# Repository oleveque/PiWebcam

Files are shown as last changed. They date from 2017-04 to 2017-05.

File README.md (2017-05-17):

# PiWebcam
* Rémi Armand, *remi.armand@ens-paris-saclay.fr*
* Olivier Lévêque, *olivier.leveque@ens-paris-saclay.fr*

Ce projet, proposé en M2 FeSUP GE à l'École Normale Supérieure Paris-Saclay, a pour objectif de réaliser un système permettant de commander l’orientation d’une webcam à partir d’un serveur web embarqué. Il se base sur l'utilisation d'une *Raspberry Pi 3* et d'un microcontrôleur *AVR-T32U4* (similaire à une *Arduino Leonardo*).

Ce système, nommé *PiWebcam*, vous est présenté en image ci-dessous.
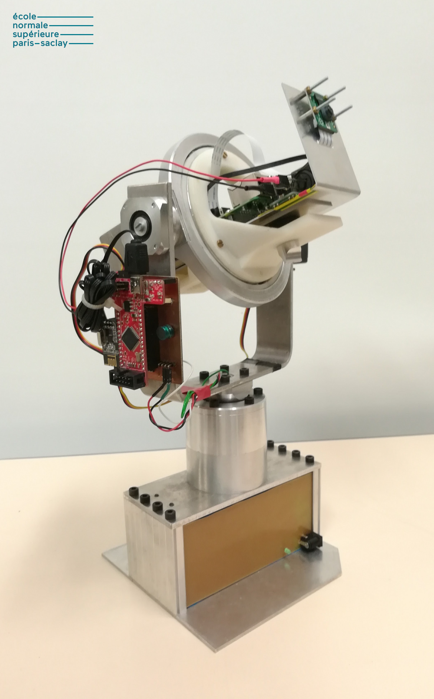
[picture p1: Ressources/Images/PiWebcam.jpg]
PiWebcam


Nous décrirons dans ce manuel son fonctionnement et nous détaillerons son installation et sa configuration.

La chronologie adoptée sera la suivante :
1. Description globale du système ;
2. Configuration du microcontrôleur *AVR-T32U4* ;
3. Installation et configuration de l'ensemble du système Linux sur *Raspberry Pi 3*.

## Description globale du système
Le système PiWebcam répond à la problématique suivante.
> Piloter une webcam à distance en commandant son orientation et son zoom à l’aide d’un serveur embarqué.

La partie matériel, nommé *Cardan 3 axes* et permettant l'orientation de la caméra, est issue d'un projet ultérieur. Seul l'étage d'alimentation a été révisé et une *Raspberry Pi 3* + *PiCamera v2.1* ajoutées. Le diagramme de définition de bloc suivant permet de décomposer le système *PiWebcam* en différents sous-systèmes que nous décrirons dans ce document.

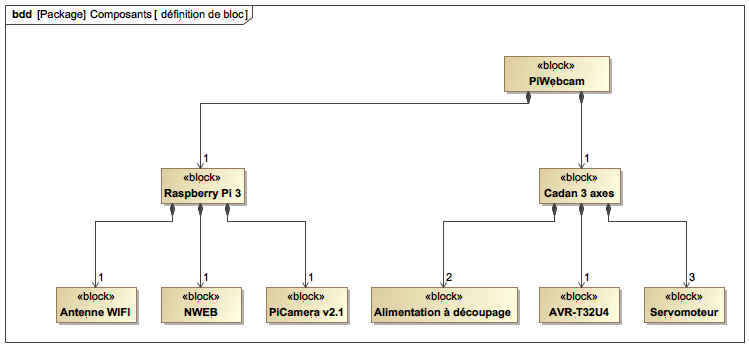
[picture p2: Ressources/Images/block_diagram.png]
Diagramme de définition de bloc


### Cardan 3 axes
Ce sous-système est composé de 2 servomoteurs ([*HS-5565MH*](Ressources/Datasheets/hs5565.pdf)) commandés en position assurant la rotation de la caméra autour de l'axe de roulis et l'axe de tangage, et d'un servomoteur ([*HS-805BB*](Ressources/Datasheets/hs805.pdf)) modifié assurant la rotation de la caméra autour de l'axe de lacet. Ce dernier est commandé en vitesse et permet une rotation totale de la caméra autour de son axe puisque sa butée mécanique a été retirée et son potentiomètre de recopie remplacé par un pont diviseur de tension.

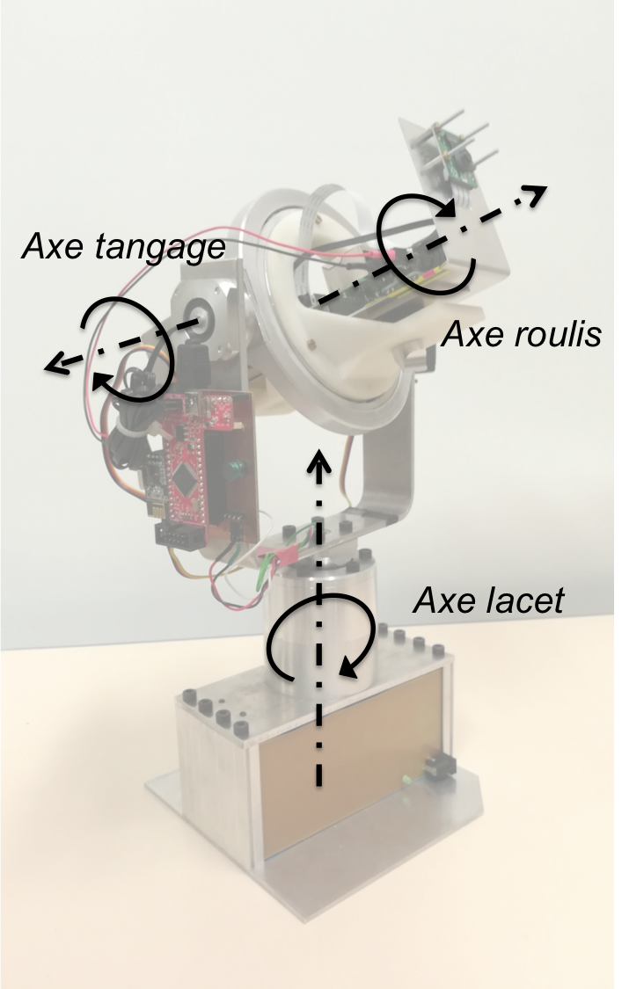
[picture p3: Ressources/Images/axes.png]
axes


Le schéma suivant décrit sommairement le système.

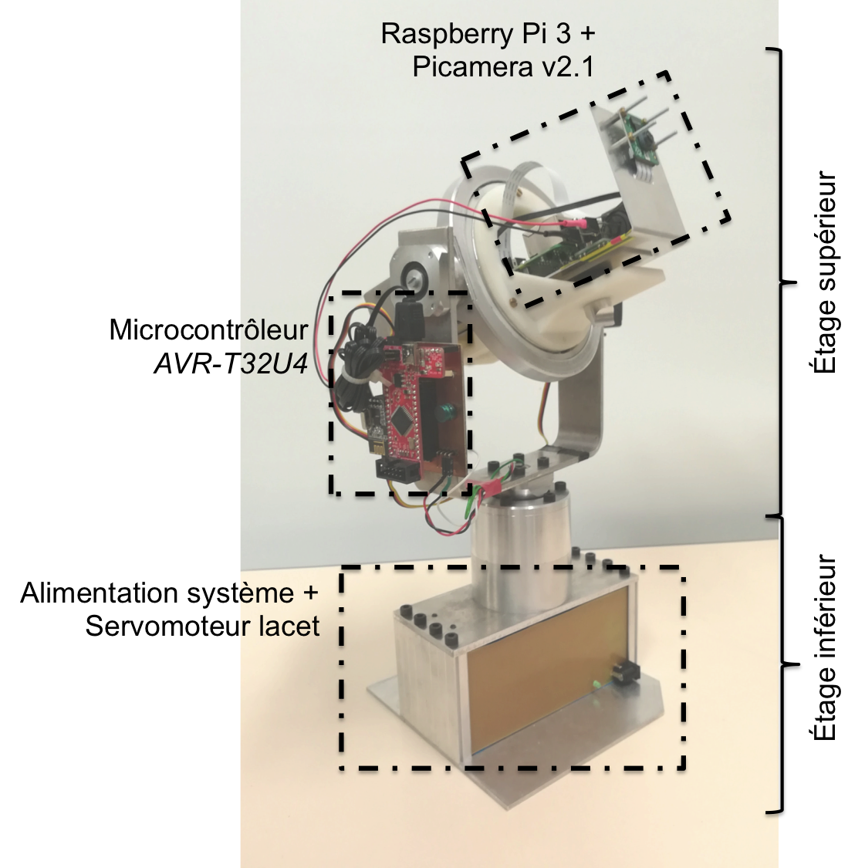
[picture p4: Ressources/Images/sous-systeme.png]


La liaison électrique entre l'étage supérieur et inférieur est assuré par des contacts glissants, permettant une rotation complète de l'étage supérieur.

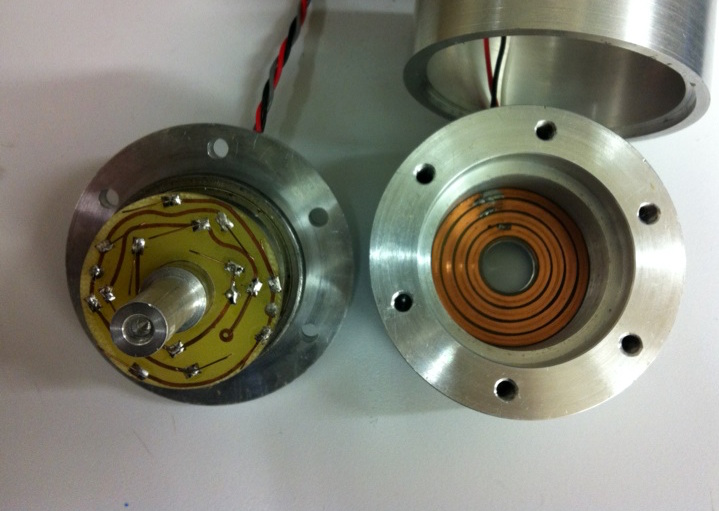
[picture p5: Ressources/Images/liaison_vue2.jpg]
contacts


L’étage d'alimentation est situé dans la botte du système (étage inférieur) et est assuré par 2 alimentations à découpage (*LM2596* et *MP2307*) délivrant (respectivement) 5V et 7V. Les fichiers *EAGLE* de cet étage sont disponibles dans l'archive du projet.
* Les 5V permettent l’alimentation du servomoteur inférieur assurant la rotation autour de l'axe de lacet ;
* Les 7V permettent l’alimentation des servomoteurs restants, du microcontrôleur, et de la Raspberry. Deux régulateurs linéaires (*L7805CV* et *79ABN05A*) permettent de fournir les 3.3V nécessaire au microcontrôleur et une 3ième alimentation à découpage (*MP2307*) permet de fournir 5V à la Raspberry. Sur cette dernière alimentation, une capacité de 2200uF a été ajoutée en entrée pour diminuer les chutes de tension lors des appels de courant des servomoteurs.

Le schéma suivant illustre la répartion de l'alimentation au sein du système.

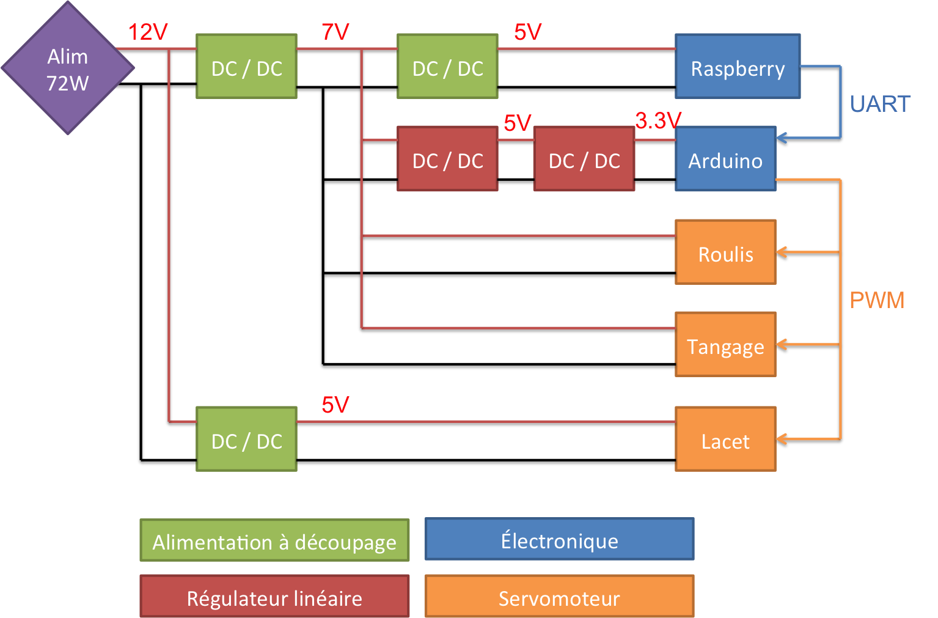
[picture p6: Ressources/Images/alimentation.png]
Schéma d'alimentation


La carte de développement utilisé est une *AVR-T32U4* dont l'architecture est inspirée d’une *Arduino Leonardo*. Elle peut être programmée à partir de l’*IDE Arduino*.
Le rôle du microcontrôleur est d'assurer le pilotage des 3 servomoteurs. Les différents pins utilisés de la carte sont présentés sur le schéma suivant.

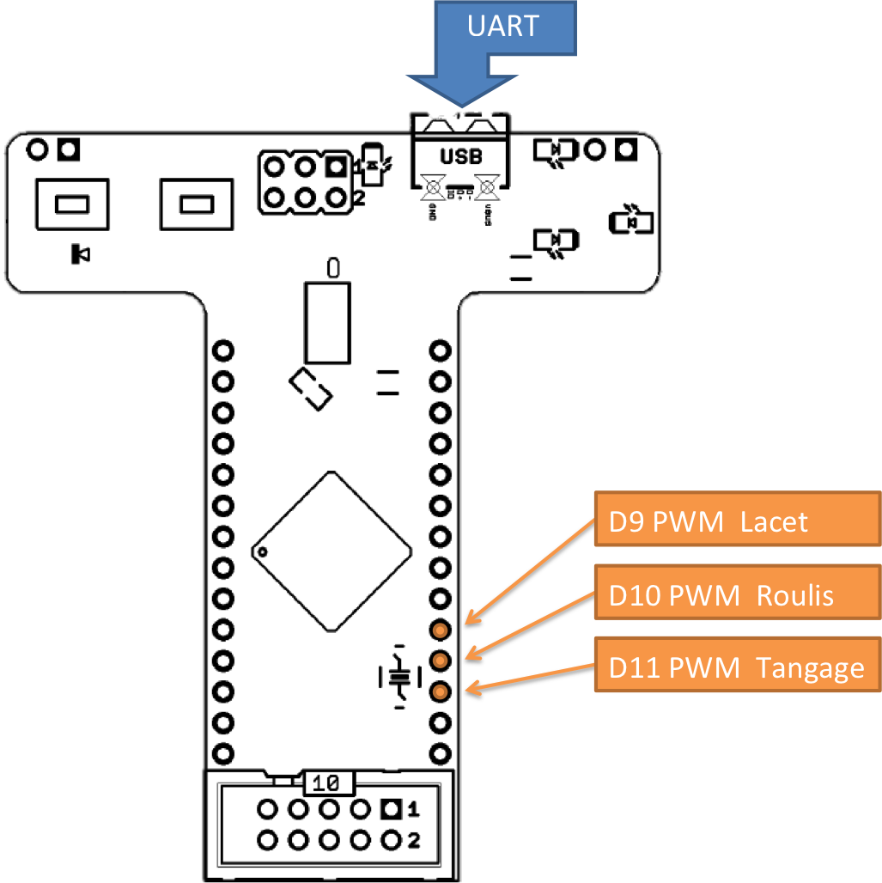
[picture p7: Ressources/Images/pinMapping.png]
Pin mapping


La communication entre la Raspberry et le microcontrôleur peut être assurée par différents types de liaison (I2C, SPI, UART). La liaison série à travers une connection USB a été retenue pour 2 raisons principales : sa facilité de mise en oeuvre et la possibilité de reprogrammer l'*AVR-T32U4* à partir de la Raspberry.

### Raspberry Pi 3 + PiCamera
La *Raspberry Pi 3* hébergera le serveur à partir duquel l'utilisateur devra se connecter pour piloter le système et visualiser le flux vidéo de la *PiCamera v2.1* (cette caméra a une résolution de 8 mégapixels permettant la mise en oeuvre d'un zoom numérique).

Le serveur diffusera une interface graphique dans lequel le flux vidéo sera streamé. Des boutons permettront de transmettre des ordres au différents servomoteurs via une liaison série entre la Raspberry et le microcontrôleur.

Un screenshot de cette interface vous est présenté ci-dessous.

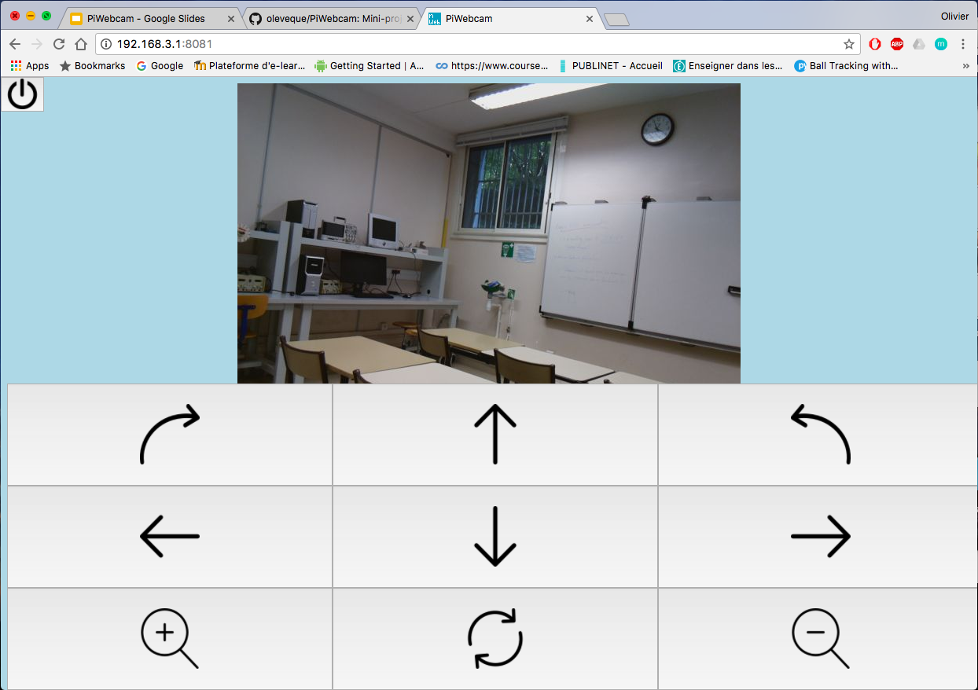
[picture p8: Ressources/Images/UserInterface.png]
User interface


Afin de mieux visualiser les flux d'informations circulant au sein de la Raspberry, le diagramme de bloc interne ci-dessous illustre les flux principaux.

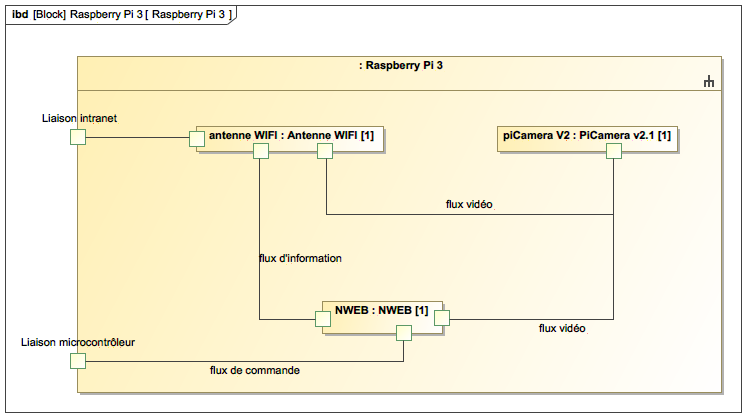
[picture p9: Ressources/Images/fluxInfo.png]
Diagramme Interne


## Configuration du microcontrôleur *AVR-T32U4*
Pour configurer le microcontrôleur *AVR-T32U4*, il est nécessaire de télécharger l'[IDE Arduino](https://www.arduino.cc/en/Main/Software). Il ne vous restera plus qu'à reprogrammer la carte avec l'un des codes *.ino* disponiblent dans le dossier `Arduino/config` (en choissisant le type de board : *Arduino Leonardo*).
Deux codes vous sont proposés :
* `ArduinoPWM.ino` utilisant la blibliothèque *Servo* d'Arduino pour générer la PWM de commande des servomoteurs ;
* `MyOwnPWM.ino` exploitant les capacités matérielles du microcontrôleur pour générer les PWM. Pour mieux comprendre son fonctionnement, vous pouvez consulter [ce lien](http://r6500.blogspot.ca/2014/12/fast-pwm-on-arduino-leonardo.html) et/ou étudier le code `PWM.ino` dans le dossier `Arduino` qui permet de générer des signaux PWM sur les pins D9, D10, D11 de l'*AVR-T32U4*.

Par défaut, ces codes permettent de commander les servomoteurs via une communication unidirectionnelle série de la Raspberry vers le port `Serial0` du microcontrôleur à la vitesse de *9600 baud*.

Les messages à envoyer sont de simples octets répertoriés dans le tableau ci-dessous.

| Octet | Signification |
| ----- | --- |
| `#` | Retour à la position d'origine |
| `@` | Stopper le mouvement et maintenir la position |
| `U` | Rotation autour de l'axe de tangage dans le sens positif |
| `D` | Rotation autour de l'axe de tangage dans le sens négatif |
| `R` | Rotation autour de l'axe de lacet dans le sens positif |
| `L` | Rotation autour de l'axe de lacet dans le sens positif |
| `W` | Rotation autour de l'axe de roulis dans le sens positif  |
| `V` | Rotation autour de l'axe de roulis dans le sens négatif  |

Il est possible d'envoyer un ordre similtanément aux 3 servomoteurs en transmettant l'octet `#` suivit respectivement des positions angulaires des servomoteurs associé au roulis, au tangage et la vitesse angulaire du servomoteur associé au lacet, en séparant les données par un caractère quelconque : par exemple `#350/-260/40`.

## Installation et configuration de l'ensemble du système Linux sur *Raspberry Pi 3*
1. Installation de Raspbian ;
2. Configuration du point d’accès Wifi ;
3. Configuration du streaming vidéo pour une *PiCamera* ;
4. Installation du serveur *nweb* modifié ;
5. Configuration de la communication série entre l'Arduino et Linux TTY ;
6. Configuration du lancement automatique des différents processus au démarrage du système.

Une fois configuré, l'interface de pilotage est accéssible à l'adresse `192.168.3.1:8081` sous réserve d'être connecté au réseau Wifi `PiWebcam` (mot de passe : `mdppiwebcam`) généré par le système.

### Installation de Raspbian
Pour télécharger l'image, rendez-vous sur la [page officiel](https://www.raspberrypi.org/downloads/raspbian/).
Suivez le [guide d'installation](https://www.raspberrypi.org/documentation/installation/installing-images/) si vous ne savez pas (ou plus) comment installer cette image sur une carte SD.

### Configuration du point d’accès Wifi
La configuration du point d'accès Wifi est inspiré de [ce tutoriel](https://www.g33k-zone.org/post/2016/05/11/Configurer-le-Raspberry-Pi-en-point-d-acc%C3%A8s-Wifi).

Cette configuration est valable pour une *Raspberry Pi 3* disposant d'un module Wifi intégré. Il est cependant possible d'effectuer une configuration similaire sur un autre modèle à l'aide d'un dongle Wifi.

**Remarque :** Pour effectuer cette configuration, il est nécessaire d'être directement connecté à la Raspberry avec un moniteur, un clavier + souris, et une connection internet.

Commencez par installer les packages *dnsmasq* et *hostapd*.
```
sudo apt-get install dnsmasq hostapd
```

La première étape consiste à forcer l'adresse IP pour le point d'accès. Par défaut, le wifi de Raspberry étant en *dhcp*, nous allons devoir éditer `/etc/dhcpcd.conf` pour forcer une adresse IP statique (`192.168.3.1` dans notre cas), en ajoutant les lignes suivantes :
```
interface wlan0  
   static ip_address=192.168.3.1/24
```

Ensuite, nous allons bloquer la négociation automatique de bail dans le fichier `/etc/network/interfaces`.
Il faut rechercher le bloc suivant :
```
allow-hotplug wlan0  
iface wlan0 inet manual  
 #   wpa-conf /etc/wpa_supplicant/wpa_supplicant.conf
```

 Il suffit de commenter la ligne d'appel à `wpa_supplicant.conf` (en ajoutant le `#`).

Nous pouvons maintenant redémarrer le wifi à l'aide de la commande suivante.
```
sudo service dhcpcd restart
```

*hostapd* est le logiciel qui permet de gérer le point d'accès, il est donc le coeur de notre système. Sa configuration se fait dans le fichier `/etc/hostapd/hostapd.conf` qu'il faut créer :

```
cd /etc/hostapd/
sudo touch hostapd.conf
sudo nano hostapd.conf
```

Et le remplir avec :
```
# Nom de l'interface wifi (celle par défaut)
interface=wlan0
# Utilisation du driver nl80211,
driver=nl80211
# Nom du réseau wifi (SSID)
ssid=PiWebcam
# Mode du wifi (bande 2.4GHz)
hw_mode=g
# Canal 6
channel=6
# Activer le 802.11n
ieee80211n=1
# Activer le WMM
wmm_enabled=1
# Activer les canaux 40MHz avec 20ns d'intervalle
ht_capab=[HT40][SHORT-GI-20][DSSS_CCK-40]
# Accepter toutes les adresses MAC (pas de restriction d'appareil)
macaddr_acl=0
# Utiliser l'authentification WPA
auth_algs=1
# Ne pas diffuser le SSID
ignore_broadcast_ssid=0
# Utiliser WPA2
wpa=2
# Utiliser une clé partagée
wpa_key_mgmt=WPA-PSK
# Mot de passe du réseau
wpa_passphrase=mdppiwebcam
# Utilisation d'AES plutôt que de TKIP
rsn_pairwise=CCMP
```

Nous pouvons alors à présent tester le fonctionnement du point d'accès.
```
sudo /usr/sbin/hostapd  /etc/hostapd/hostapd.conf
```
Cette commande lance le point d'accès et permet d'avoir le log d'activité directement dans la console. Avec un équipement wifi (gsm, tablette, portable, ...), essayez de vous connecter au réseau `PiWebcam`, normalement la tentative de connexion apparaît.

Une fois que le point d'accès fonctionne, coupez le (*Ctrl+C*) et placez le en démarrage automatique, en éditant le fichier `/etc/default/hostapd`.
```
#DAEMON_CONF=""         =>           DAEMON_CONF="/etc/hostapd/hostapd.conf"
```

*dnsmasq* est un petit serveur DNS qui intègre un serveur *DHCP*. Il permettra d'attribuer les adresses IP aux clients qui se connecteront sur le point d'accès.
Sauvegardez son fichier de configuration initial (`/etc/dnsmasq.conf`, qui n'est pas entierement commenté!) puis créez en une nouvelle version :
```
# Interface à utiliser
interface=wlan0
# Limiter le fonctionnement à l'interface déclarée
bind-interfaces
# Transférer les requêtes DNS sur les DNS d'OpenDns
server=208.67.222.222
# Ne pas forwarder les requêtes "locales" (sans nom de domaine)
domain-needed
# Fausse résolution inverse pour les réseaux privés. Toutes les requêtes DNS inverses pour des adresses IP privées (ie 192.168.x.x, etc…) qui ne sont pas trouvées dans /etc/hosts ou dans le fichier de baux DHCP se voient retournées une réponse “pas de tel domaine” (”no such domain”) au lieu d’être transmises
bogus-priv
# Plage DHCP : on attribuera les adresses IP entre 192.168.3.50 et 192.168.3.150 pour une durée de 12h
dhcp-range=192.168.3.50,192.168.3.150,12h
```

Vous avez actuellement un point d'accès fonctionnel mais limité au réseau local. La suite de ce tutoriel est facultative si vous ne souhaitez pas d'accès à internet via votre Raspberry.

Nous allons utiliser *iptables* pour ajouter des règles de routage.

Il faut commencer par modifier les règles de sécurité dans `/etc/sysctl.conf` pour autoriser le transfert IPv4 (ou IP forwarding) en décommantant la ligne suivante.
```
net.ipv4.ip_forward=1
```

Cette modification ne sera prise en compte qu'au prochain redémarrage de votre Raspberry, mais il est possible de forcer son activation immédiate à l'aide de la commande suivante.
```
sudo sh -c "echo 1 > /proc/sys/net/ipv4/ip_forward"
```

Maintenant que le transfert IPv4 est autorisé, nous allons créer les règles qui vont transférer les requêtes Wifi vers le port ethernet en excécutant les commandes suivantes.
```
sudo iptables -t nat -A POSTROUTING -o eth0 -j MASQUERADE  
sudo iptables -A FORWARD -i eth0 -o wlan0 -m state --state RELATED,ESTABLISHED -j ACCEPT  
sudo iptables -A FORWARD -i wlan0 -o eth0 -j ACCEPT
```

Pour que ces règles soient appliquées à chaque démarrage, nous allons commencer par les sauvegarder dans un fichier `/etc/iptables.ipv4.nat`.
```
sudo sh -c "iptables-save > /etc/iptables.ipv4.nat"
```

Ensuite, nous allons créer un fichier qui sera appelé automatiquement au démarrage du serveur *dhcp*
```
sudo echo "iptables-restore < /etc/iptables.ipv4.nat" > /lib/dhcpcd/dhcpcd-hooks/70-ipv4-nat
```

Pour pouvoir tester votre système sans avoir à le rebooter, il suffit de lancer les daemons manuellement.
```
sudo service hostapd start  
sudo service dnsmasq start
```

Vous disposez à présent dans point d'accés Wifi via la Raspberry.

### Configuration du streaming vidéo pour une *PiCamera*
Pour le streaming vidéo, nous utilisons le package *mjpg-streamer*. Pour plus d'informations, suivez [ce lien](https://doc.ubuntu-fr.org/mjpg-streamer).

Avant de commencer, assurez vous que le package *subversion* est bien installé.
```
sudo apt-get install subversion
```

L'installation de *mjpg-streamer* peut alors commencer.
```
sudo apt-get install libjpeg62-dev
sudo apt-get install libjpeg-dev
svn checkout svn://svn.code.sf.net/p/mjpg-streamer/code/  /mjpg-streamer
cd /mjpg-streamer/mjpg-streamer
sudo make
sudo make install
```

Pour pouvoir lancer le streaming vidéo, il faut charger le module `bcm2835-v4l2` à l'aide de la commande suivante à chaque démarrage de la Raspberry. La camera doit être branché au démarrage. Pour plus d'informations, consultez [ce lien](http://www.epingle.info/?p=3224).
```
sudo modprobe bcm2835-v4l2
```

Pour éviter d’avoir à exécuter cette commande à chaque démarrage, il suffit d’ajouter le module `bcm2835-v4l2` à l’ensemble des modules lancés par Linux au démarrage en ajoutant le nom du module à la fin du fichier  `/etc/modules`.

Le streaming vidéo se lance à l'aide de la commande suivante.
```
mjpg_streamer -i "/usr/local/lib/input_uvc.so -d /dev/video0 -f 24 -r 320x180" -o "/usr/local/lib/output_http.so -n -w /usr/local/www -p 8001"
```
La vérification de l'existence de `/dev/video0` permet de savoir sur le module s’est bien lancer au démarrage.

Le flux vidéo de la *PiCamera* devrait à présent être accessible à l'adresse `192.168.3.1:8001`.

### Installation du serveur *nweb* modifié
La serveur web mis en oeuvre repose sur le serveur *nweb* proposé par [Ankush Agarwal](https://github.com/ankushagarwal/nweb). Nous l'avons légèrement modifié pour qu'il prennent en compte la gestion de *cgi*.

Pour l'installer, placez le fichier `nweb23.c` et le dossier `serveur` contenant le site dans un répertoire sensible (et non pas dans un répertoire système comme `/` ou `/temp`). Par exemple dans `/home`. Puis rendez le dossier lisible.
```
chmod ugo+r /home/serveur
```
Compilez ensuite le serveur *nweb* et rendez le executable.
```
cc /home/nweb23.c -o /home/nweb
chmod 777 /home/nweb
```
Décidez ensuite du numéro du port que vous utiliserez (ici *8081*). Puis lancez *nweb* à l'aide de la commande suivante.
```
/home/nweb 8081 /home/serveur
```

Voilà, le serveur *nweb* fonctionne à présent et l'interface de pilotage du système *PiWebcam* est disponile à l'adresse `192.168.3.1:8081`

### Configuration de la communication série entre l'Arduino et Linux TTY
Pour configurer la connection Série entre la Raspberry et le microcontrôleur avec la bonne parité, vitesse... excécutez la commande suivante. Pour plus d'information, consultez [ce lien](http://playground.arduino.cc/Interfacing/LinuxTTY).
```
stty -F /dev/ttyACM0 cs8 9600 ignbrk -brkint -icrnl -imaxbel -opost -onlcr -isig -icanon -iexten -echo -echoe -echok -echoctl -echoke noflsh -ixon -crtscts
```

Pour envoyer un message de type *String* au microcontrôleur, nous utiliserons les commandes :
```
#avec fin de ligne
echo "Hello Arduino" > /dev/ttyUSB0

#sans fin de ligne
echo -n "Hello" > /dev/ttyUSB0
```

Pour lire un message de type String envoyé du microcontrôleur, nous utiliserons la commande :
```
tail -f /dev/ttyUSB0
```

### Lancement des différents processus au démarrage de la Raspberry
Le lancement du serveur *nweb* et du streaming vidéo au démarrage de la Raspberry se fait à l'aide du fichier `lancementServeur.sh`. (Nous supposerons que ce fichier disponible dans l'archive du projet et se trouve dans `/home`).

Déplacez le script shell dans le répertoire `/etc/init.d` qui contient les différents scripts lancés au démarrage, et rendait le executable via les commandes suivantes.

```
sudo mv /home/lancementServeur.sh /etc/init.d/lancementServeur
sudo chmod 777 /etc/init.d/lancementServeur
```

Les liens symboliques associés au fichier `lancementServeur` pour son démarrage et son arrêt au lancement et à l'arrêt de la Raspberry sont générés à l'aide de la commande suivante.
```
sudo update-rc.d lancementServeur defaults
```
Le lien symbolique créé dans `rc3.d` est `S02lancementserveur`. Nous pouvons renommer le lien en `S99lancementserveur` pour qu'il se lance en dernier.

À présent le système *PiCamera* est entièrement installé et configuré.

Enjoy & have a lot of fun...

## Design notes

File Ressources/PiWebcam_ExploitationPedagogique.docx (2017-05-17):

TP PiWebcam


Le système PiWebcam est en système pluri-technique répondant à la problématique suivante.

“Piloter une webcam à distance en commandant son orientation et son zoom à l’aide d’un serveur embarqué.”

Une documentation technique associée est disponible, ainsi que la datasheet de la plupart des éléments composants le système.

Nous explorerons durant ce TP le fonctionnement d’un servomoteur usuel et la génération de ses signaux de commande. Nous mettrons en œuvre une PWM hardware en manipulant les registres spécifiques à l’Atmega32U4.

1. Approche globale

Attention : Avant la mise sous tension du système, veuillez lire attentivement la documentation associée et répondre aux questions suivantes.

Q1.1. Établir un tableau récapitulatif des puissances électriques consommés par les différents sous-systèmes de la PiWebcam :

- Servomoteurs (alimenté en 5V, 7V) ;
- Raspberry ;
- microcontrôleur.

Q1.2. Trois adaptateurs secteurs vous sont proposés (1,8W, 30W et 72W). En déduire de la Q1 l’adaptateur le plus approprié pour le bon fonctionnement du système. Présenter et justifier votre résultat à l’enseignant pour qu’il puisse le valider votre choix.

Q1.3. Un condensateur 2200uF a été ajouté en amont de l’alimentation à découpage associée à la Raspberry. Expliciter son rôle ?

Q1.4. Quel type de communication entre la Raspberry et le microcontrôleur est-il mis en œuvre ? D’autres liaisons pourraient-elles être envisagées ?

Q1.5. Les servomoteurs sont-ils commandés en position et/ou vitesse ? Quelles grandeurs physiques les commandent ?

- Tension ;
- Courant ;
- Autres (précisez…)

À présent, alimentez le système avec l’adaptateur retenu et validé à la Q2 et prenez en main le système en vous connectant en Wifi à son intranet.

SSID : PiWebcam

Mot de passe : mdppiwebcam

Attendre deux bonnes minutes que les processus de la Raspberry (mise en route du serveur web, streaming de la webcam…) s’exécutent correctement puis ouvrir un navigateur et taper l'adresse suivante pour accéder à son interface graphique.

192.168.3.1:8081

Manipuler le système via cette interface pour le prendre en main.

Attention : L’extinction de la PiWebcam se fait via l’interface graphique. Ce n’est qu’une fois la LED verte de la Raspberry éteinte que vous pouvez retirer l’alimentation.

2. Commande en position d’un servomoteur

Q2.1. En vous inspirant du programme .ino présent dans le dossier /Arduino/config/ArduinoPWM qui configure le microcontrôleur, écrire un programme simple sous l’IDE Arduino qui permet de piloter la position angulaire de l’arbre de sortie du servomoteur Roulis (pin D10) par largeur d'impulsion. Vous pourrez vous aider de la bibliothèque Servo d’Arduino.

Q2.2. À l’aide d’un oscilloscope, vérifier que la PWM générée est bien celle attendue et tracer à l’aide d’Excel un graphe présentant la valeur angulaire de l’arbre de sortie en fonction de la largeur d’impulsion du signal envoyé (la largeur comprise sera entre 700us à 2200us). Quelle est la nature de cette relation ? Existe-t-il des zones mortes ?

Q2.3. Quels phénomènes non désirés remarqués vous sur la commande des servomoteurs ? Ces phénomènes sont particulièrement visibles sur le système PiWebcam dans sa position de repos (position adoptée au démarrage). Justifier à l’aide de l’oscilloscope que ces phénomènes proviennent des signaux PWM envoyés aux servomoteurs.

3. Générations de PWM hardware

Pour supprimer les phénomènes constatés à la Q8, il est nécessaire de générer des signaux PWM matériellement (sans utiliser la bibliothèque Servo d’Arduino mais les ressources matérielles de l’Atmega32U4).

Q3.1. À partir des datasheets disponibles sur le microcontrôleur, expliquer brièvement comment peut-on générer une PWM à partir d’un Timer. Quels types de PWM peut-on générer avec un Atmega32U4?

Q3.2. Quels périodes doivent avoir les signaux PWM ?

Q3.3. Vu les pins sur lesquels sont branchés les servomoteurs de la PiWebcam, quel Timer pouvons nous utiliser ? Quelle est sa résolution (en nombre de bits) ? Sachant que l’on souhaite une résolution angulaire de 0,1°, sera-t-elle suffisante ? Justifier vos affirmations à l’aide des datasheets des servomoteurs.

Q3.4. Quels registres permettent de configurer le Timer ?

Nous souhaitons mettre en œuvre un signal Fast PWM 16bit utilisant le Timer 1 sur le pin D10 du microcontrôleur, afin de commander le Servo HS-5565 assurant la rotation autour de l'axe de roulis.

Q3.5. À l’aide des réponses précédentes, déterminer le prescaler du Timer et sa valeur MAX.

Q3.6. Comparer vos valeurs d’initialisation des registres avec ceux du programme PWM.ino disponible dans le dossier Arduino. Sont-ils semblables ? Commenter et argumenter vos différences.

Q3.7. Tester le programme et vérifier à l’oscilloscope la PWM généré. Est-elle celle escomptée ?

Q3.8. Le programme MyOwnPWM.ino reprend le programme ArduinoPWM.ino en n’utilisant plus la bibliothèque Servo mais en générant une Fast PWM 16bit comme vu précédemment. Flasher le programme dans le microcontrôleur, retourner sur l’interface graphique de la PiWebcam et piloter le système. Les phonèmes constatés à la Q8 sont-ils toujours présents ? Commenter et justifier vos affirmations.

Rémi Armand Page 1 sur 1 Olivier Lévêque

École normale supérieure Paris-Saclay 17 May 2017

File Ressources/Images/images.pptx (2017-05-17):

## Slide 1

Alim
72W

12V

7V

5V

DC / DC

DC / DC

Raspberry

DC / DC

5V

DC / DC

3.3V

Arduino

UART

Roulis

PWM

Tangage

DC / DC

5V

Lacet

Alimentation à découpage

Électronique

Régulateur linéaire

Servomoteur

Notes: Schéma d’alimentation

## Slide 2

UART

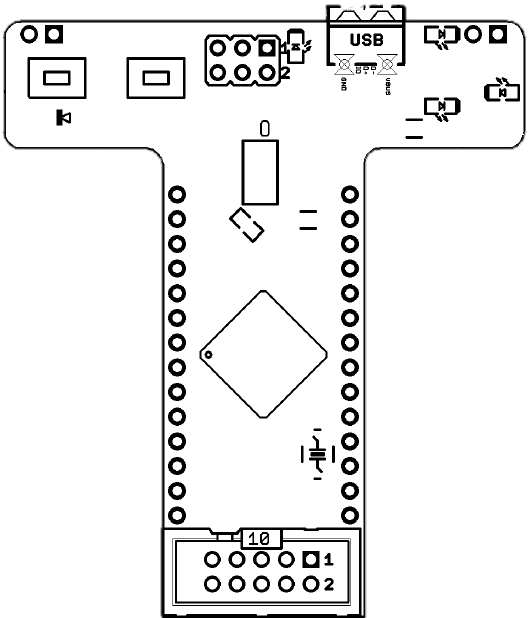
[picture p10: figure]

D9 PWM Lacet

D10 PWM Roulis

D11 PWM Tangage

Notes: Schéma pin mapping

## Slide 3

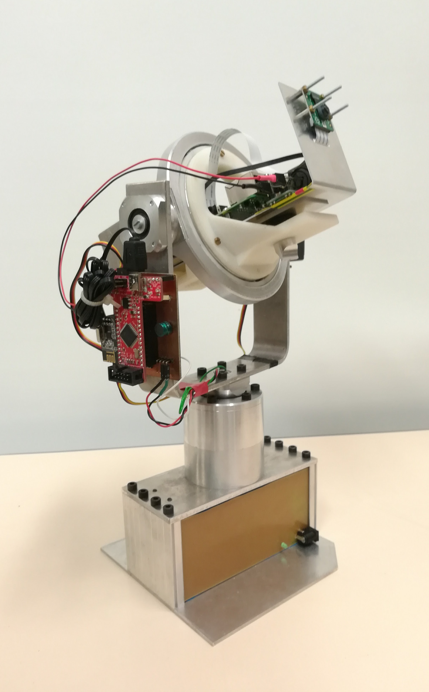
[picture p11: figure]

Axe tangage

Axe roulis

Axe lacet

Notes: Axes de la PiWebcam

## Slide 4

Raspberry Pi 3 +
Picamera v2.1

Étage supérieur

Microcontrôleur
AVR-T32U4

Alimentation système +
Servomoteur lacet

Étage inférieur

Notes: Sous-systèmes

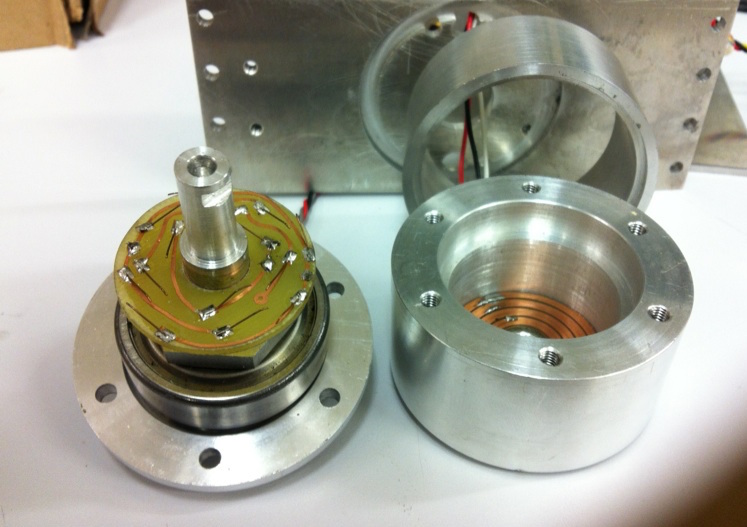
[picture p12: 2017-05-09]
Ressources/Images/liaison_vue1.jpg

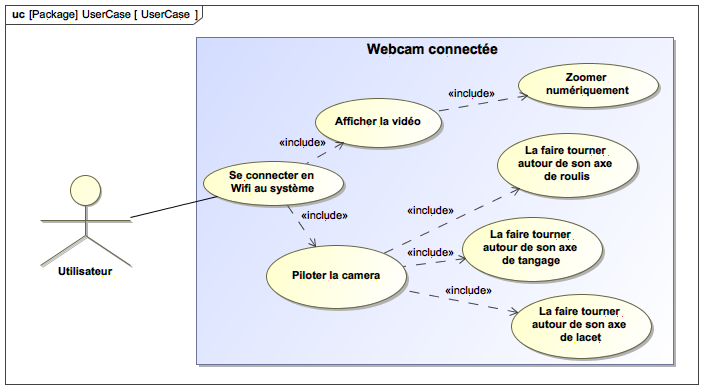
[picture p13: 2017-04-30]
Ressources/Images/UserCase.png

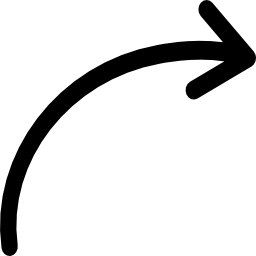
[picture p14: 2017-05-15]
RaspberryPi/serveur/right-roulis.png

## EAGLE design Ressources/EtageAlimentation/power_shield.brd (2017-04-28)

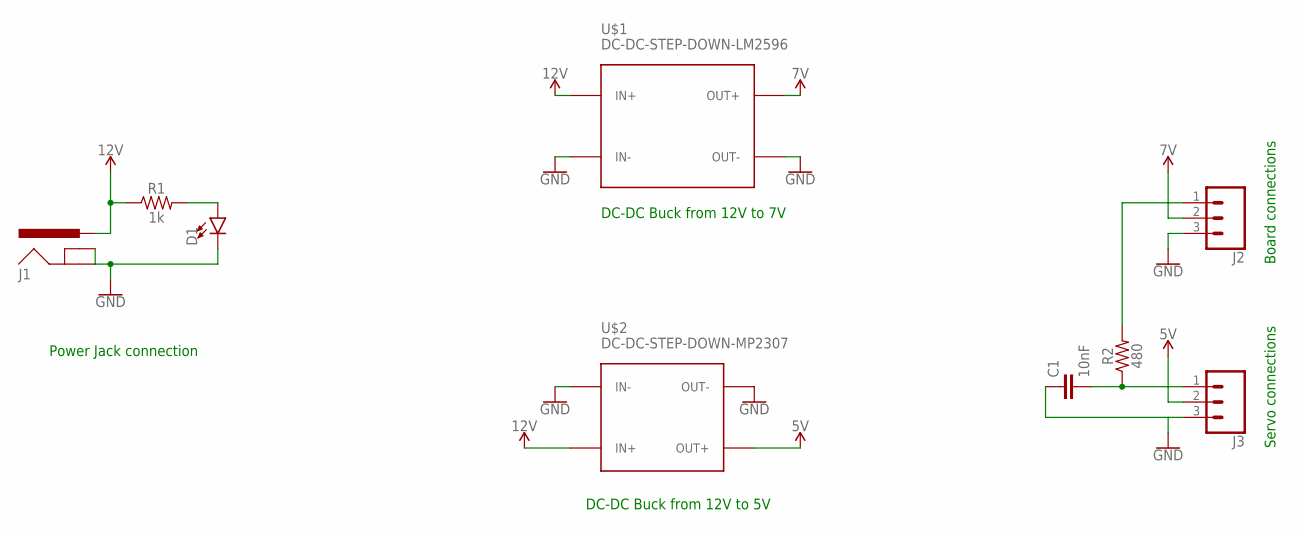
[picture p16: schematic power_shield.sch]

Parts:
C1: 10nF; 1206
D1: LED5MM; LED_5MM
J1: POWER_JACKPTH_LOCK; POWER_JACK_PTH_LOCK
J2, J3: CONN_03; 1X03
R1: 1k; 1206
R2: 480; 1206
U$1: DC-DC-STEP-DOWN-LM2596
U$2: DC-DC-STEP-DOWN-MP2307

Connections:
5V: J3.2, U$2.OUT+
12V: J1.PWR, R1.1, U$1.IN+, U$2.IN+
GND: C1.1, D1.K (C), J1.GND, J1.GNDBREAK, J2.3, J3.3, U$1.IN-, U$1.OUT-, U$2.IN-, U$2.OUT-
unnamed: D1.A, R1.2
unnamed: C1.2, J3.1, R2.1
unnamed: J2.1, R2.2
VCC: J2.2, U$1.OUT+

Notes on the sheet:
Board connections
Servo connections
DC-DC Buck from 12V to 5V
DC-DC Buck from 12V to 7V
Power Jack connection

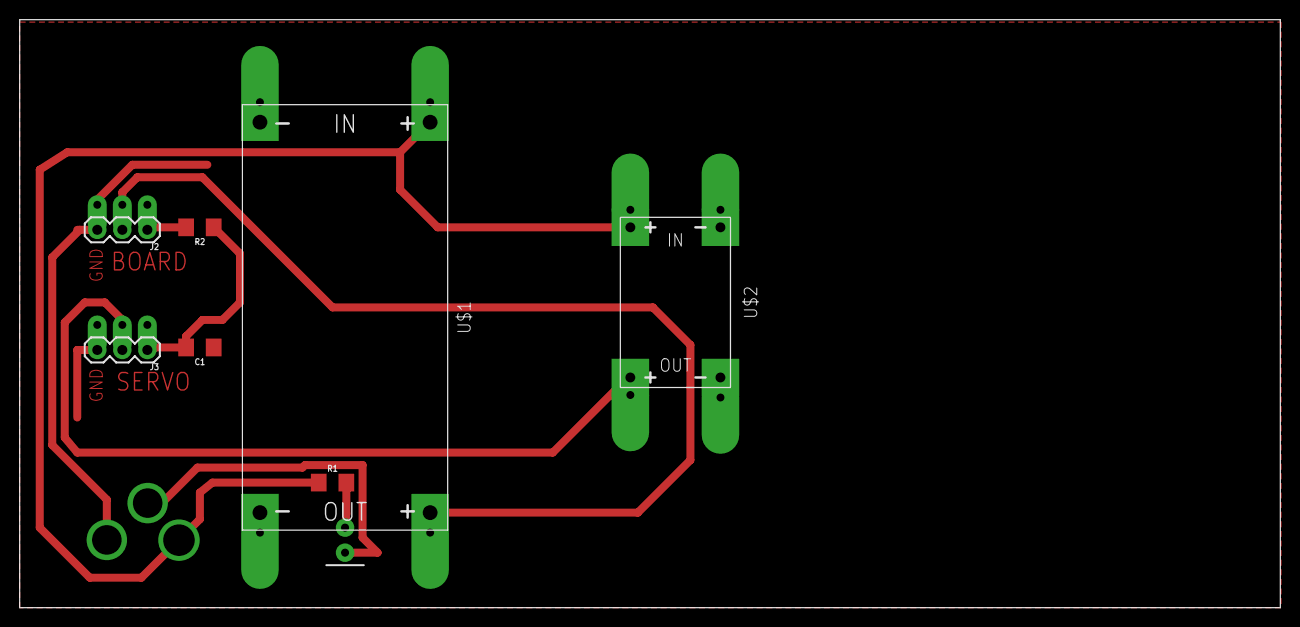
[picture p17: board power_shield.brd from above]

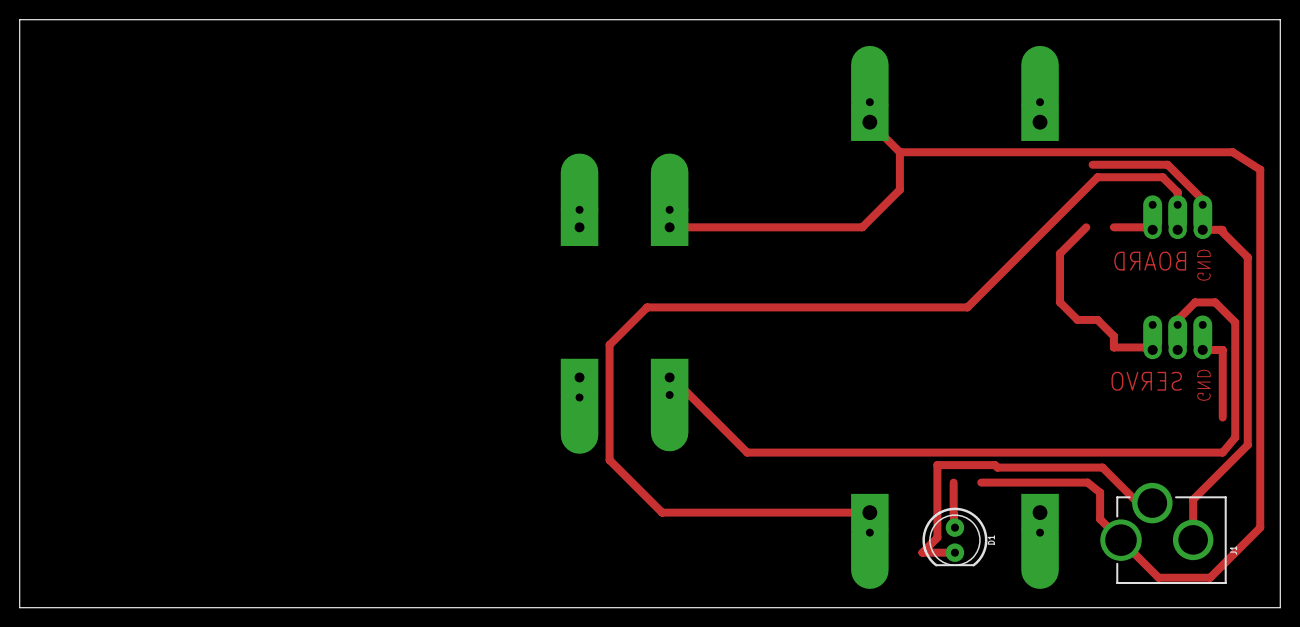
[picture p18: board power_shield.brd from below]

Board: 2 copper layers, 127.9 x 59.7 mm, 9 parts (2 on the bottom side), 7 nets.

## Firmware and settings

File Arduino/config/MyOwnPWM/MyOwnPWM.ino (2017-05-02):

#define MICROS2PWM(x) (x/4)

#define MIDDLE_ROULIS 1450
#define MIDDLE_TANGUAGE 1500
#define MIDDLE_LACET 1675

#define SPEED 0.03
#define MAX 19500
#define MIN -19500

int R = 0;
int T = 0;
int L = 0;

float RR = 0;
float TT = 0;

char lastByte;
int16_t cmd;

void setup() {
  Serial.begin(9600);
  Serial.setTimeout(50);
  
  init_PWM();
}

void loop() {
    char firstByte = (char)Serial.read();
    
    if (firstByte == '#') {
      TT = 0;
      RR = 0;
      lastByte = '#';
      R = Serial.parseInt();
      T = Serial.parseInt();
      L = Serial.parseInt();
      
      cmd = MIDDLE_LACET - L;
      OCR1A = MICROS2PWM(cmd);
      
      cmd = MIDDLE_ROULIS - R;
      OCR1B = MICROS2PWM(cmd);
      
      cmd = MIDDLE_TANGUAGE - T;
      OCR1C = MICROS2PWM(cmd);
    }
    
    else if (firstByte == '@') {
      lastByte = '@';
      OCR1A = MICROS2PWM(MIDDLE_LACET);
    }
    else if (firstByte == 'U' || lastByte == 'U') {
      TT++;
      lastByte = 'U';
      cmd = MIDDLE_TANGUAGE - (int)round(TT*SPEED);
      OCR1C = MICROS2PWM(cmd);
    }
    else if (firstByte == 'D' || lastByte == 'D') {
      TT--;
      lastByte = 'D';
      cmd = MIDDLE_TANGUAGE - (int)round(TT*SPEED);
      OCR1C = MICROS2PWM(cmd);
    }
    else if (firstByte == 'R') {
      lastByte = 'R';
      cmd = MIDDLE_LACET + 1500*SPEED;
      OCR1A = MICROS2PWM(cmd);
    }
    else if (firstByte == 'L') {
      lastByte = 'L';
      cmd = MIDDLE_LACET - 1500*SPEED;
      OCR1A = MICROS2PWM(cmd);
    }
    else if (firstByte == 'W' || lastByte == 'W') {
      RR++;
      lastByte = 'W';
      cmd = MIDDLE_ROULIS - (int)round(RR*SPEED);
      OCR1B = MICROS2PWM(cmd);
    }
    else if (firstByte == 'V' || lastByte == 'V') {
      RR--;
      lastByte = 'V';
      cmd = MIDDLE_ROULIS - (int)round(RR*SPEED);
      OCR1B = MICROS2PWM(cmd);
    }
    
    if (TT > MAX) TT = MAX;
    if (TT < MIN) TT = MIN;
    if (RR > MAX) RR = MAX;
    if (RR < MIN) RR = MIN;
}

void init_PWM() {
  //Définition du prescaler, du Fast PWM
  TCCR1A = 0xAA;
  TCCR1B = 0x1B;
  TCCR1C = 0;
  ICR1 = 5000;

  //Definition port de sortie
  DDRB |= 1<<5;
  DDRB |= 1<<6;
  DDRB |= 1<<7;

  //Definition largeur d'impulsion
  OCR1A = MICROS2PWM(MIDDLE_LACET);
  OCR1B = MICROS2PWM(MIDDLE_ROULIS);
  OCR1C = MICROS2PWM(MIDDLE_TANGUAGE);
}

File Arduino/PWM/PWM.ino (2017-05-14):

//Function to convert Microsecond in counter value
#define MICROS2PWM(x) (x/4)

void setup() {
  //PWM mode (mode 2): COM1x1:0 = b10
  //Waveform (mode 9): WGMn3:0 = b1001
  //Prescaler (/64): CS2:0 = b011
  TCCR1A = 0xAA;
  TCCR1B = 0x1B;
  TCCR1C = 0;

  //Max counter value = 5000
  ICR1 = 5000;

  //Define PWM output port
  DDRB |= 1<<5; //D9
  DDRB |= 1<<6; //D10
  DDRB |= 1<<7; //D11

  //Define PWM value in microsecond
  OCR1A = MICROS2PWM(1675); //D9
  OCR1B = MICROS2PWM(1450); //D10
  OCR1C = MICROS2PWM(1500); //D11
}

void loop() {
  //Nothing
}

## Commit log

2017-05-04 add TP
    [power_shield.brd, power_shield.sch]
2017-05-12 Update pin Lacet
2017-05-14 add comments PWM.ino

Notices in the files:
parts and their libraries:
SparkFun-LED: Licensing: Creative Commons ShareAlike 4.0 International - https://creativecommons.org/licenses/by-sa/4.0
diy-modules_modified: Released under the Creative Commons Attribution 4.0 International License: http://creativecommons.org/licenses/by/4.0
